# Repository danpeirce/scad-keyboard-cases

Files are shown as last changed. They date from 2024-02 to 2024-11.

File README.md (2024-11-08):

# Corne Inspired Keyboard Case Modified to use a Raspberry Pi Pico

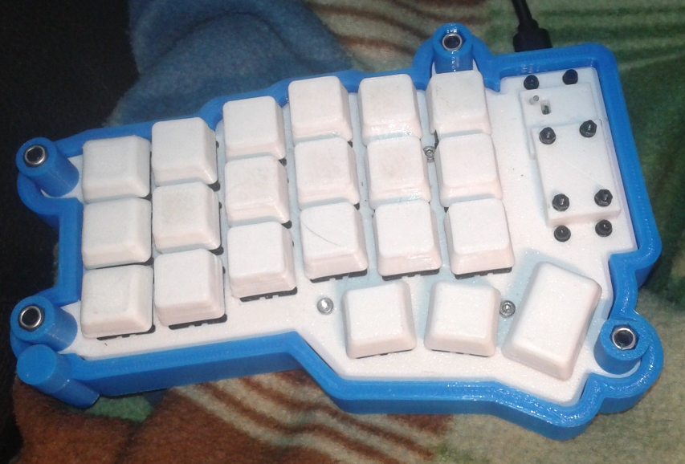
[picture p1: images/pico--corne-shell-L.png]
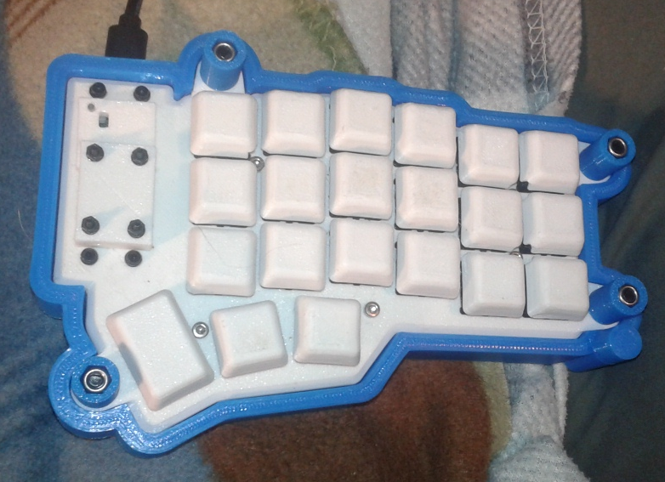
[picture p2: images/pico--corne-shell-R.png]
 

This repository is a fork of https://github.com/Lenbok/scad-keyboard-cases .
That repository is set up to allow the generation of generalized keyboard cases using
a python script to generate a base OpenSCAD design. There was already and example of a Corne case in the original repository so I have used that example as a 
starting point. I wanted that basic physical switch layout but 
also adjusted the case to permit the use of the Raspberry Pi Pico microcontroller board. The Pico required more space than the orignal MCU.
A TPU shell and guard posts were added. Also added tending pegs and internal spacers (spacers go inside shell).

Screws were added to hold it together.

* M2 x16
* M2.5 to connect top to base x10 
* M4 with locking nuts for guard posts x8

Standoffs and holes for mounting the Pico board were added. Additional mounting holes were added for small removable covers to allow for future customization.
I am using the two sides of the keyboard without direct connection between them. One customization could possibly be to add connectors for connection to the other 
side of the keyboard.

* https://datasheets.raspberrypi.com/pico/pico-datasheet.pdf

Files created prior to 2024 are from the original repository. Files specific to this fork are all modified or created in 2024.

## Added Tenting Supports

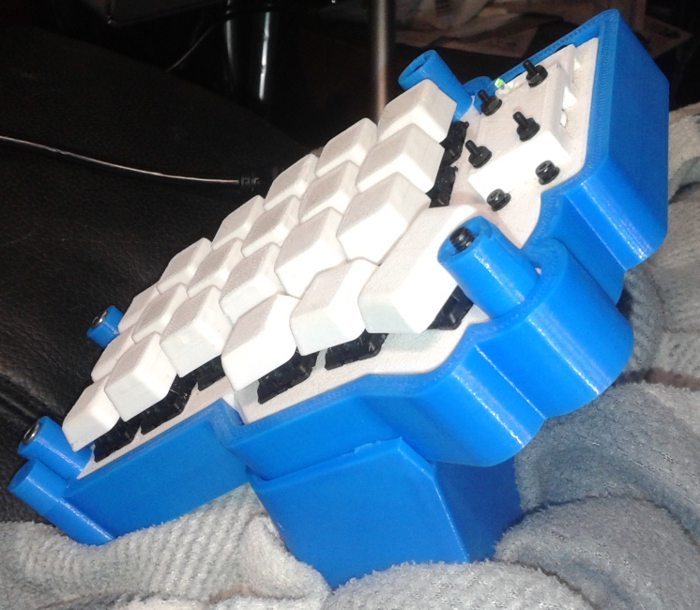
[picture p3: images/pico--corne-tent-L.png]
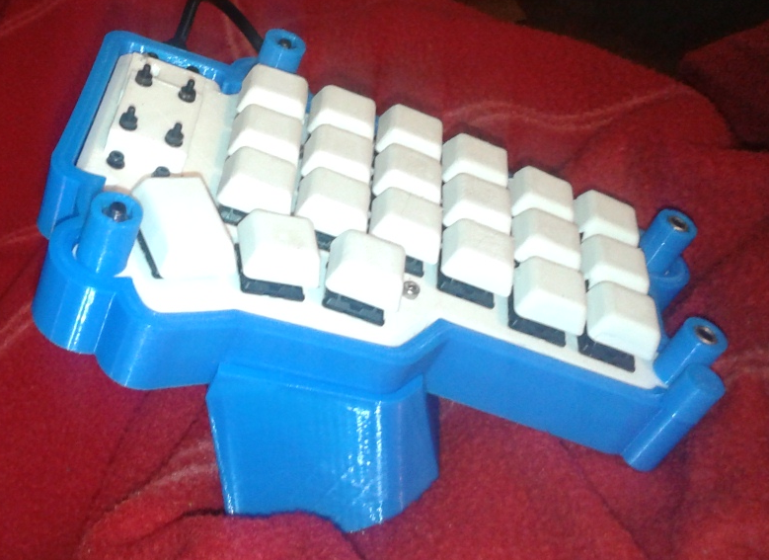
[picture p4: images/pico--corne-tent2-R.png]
 

Each side of the keyboard can be press fit into the tenting support. The supports are made of flexible TPU but have enough infill to be semi-rigid.
	 
## Pico-Corne Keyboard

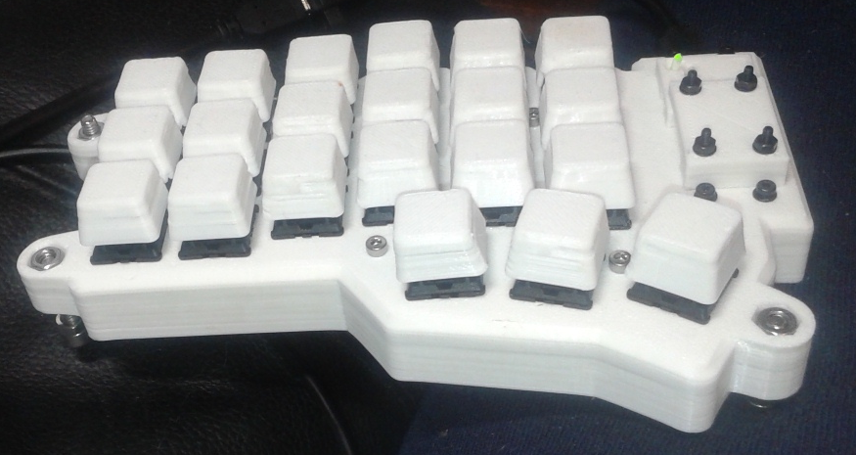
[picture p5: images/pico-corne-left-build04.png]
 

* Light from RPi Pico board piped outside case by short piece of clear PETG filament.
* Covers over Pico board area allow for customization without reprinting whole case. Also contain side
  vents for convective cooling.
* Used crkbd/stls/crkbd-case-top-pico.stl and crkbd/stls/-case-base-pico.stl for left side keyboard. The same file can be mirrored in slicing software to create right side case.
* crkbd/stls/crkbd-case-top-pico.stl and crkbd/stls/cover_trrs.stl are used as is on both left and right sides.

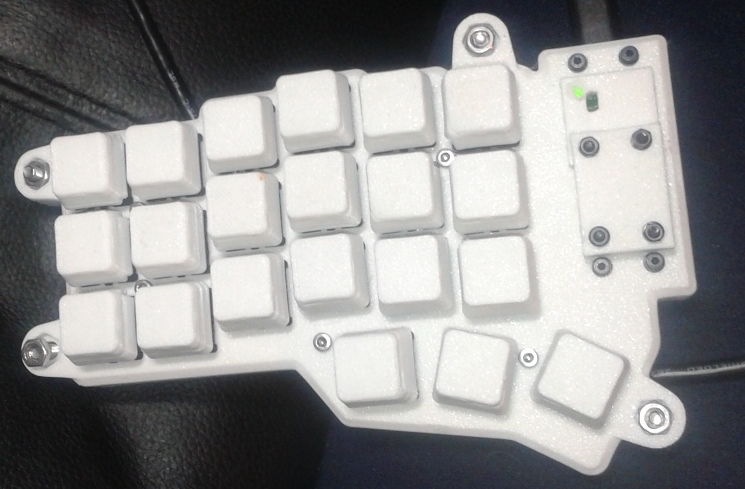
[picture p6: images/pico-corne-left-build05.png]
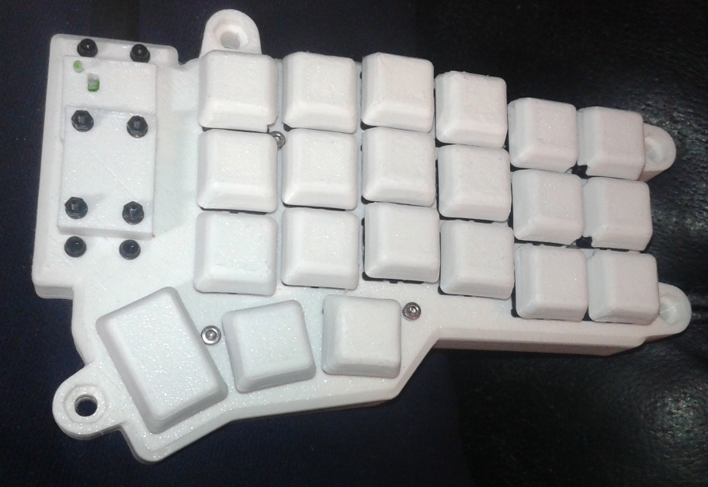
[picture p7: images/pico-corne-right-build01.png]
 

### Construction

Image links to youtube! construction of left side of keyboard (https://www.youtube.com/watch?v=Hs4WmTu5av8)

* The image above is a link to a youtube video showing how the parts of the left side of the keyboard go together. This video was created using Blender and as such is CGI.
* The images below are photographs of the actual physical keyboard.

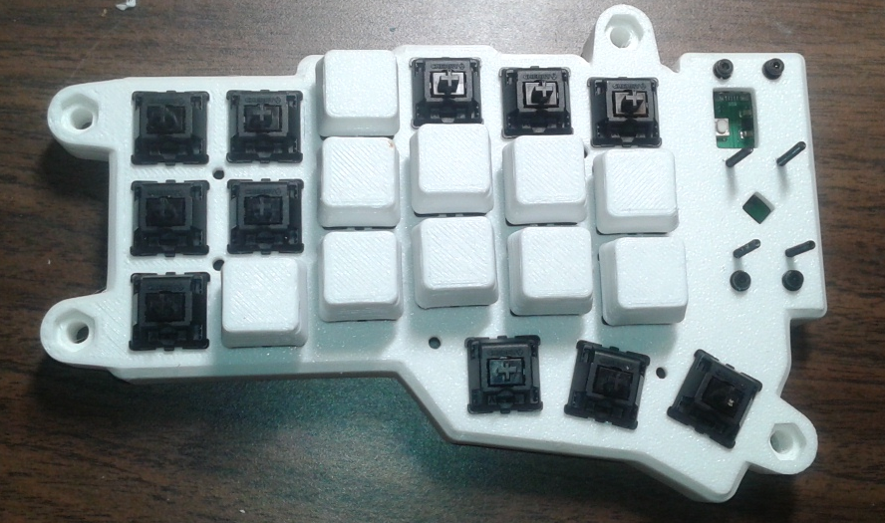
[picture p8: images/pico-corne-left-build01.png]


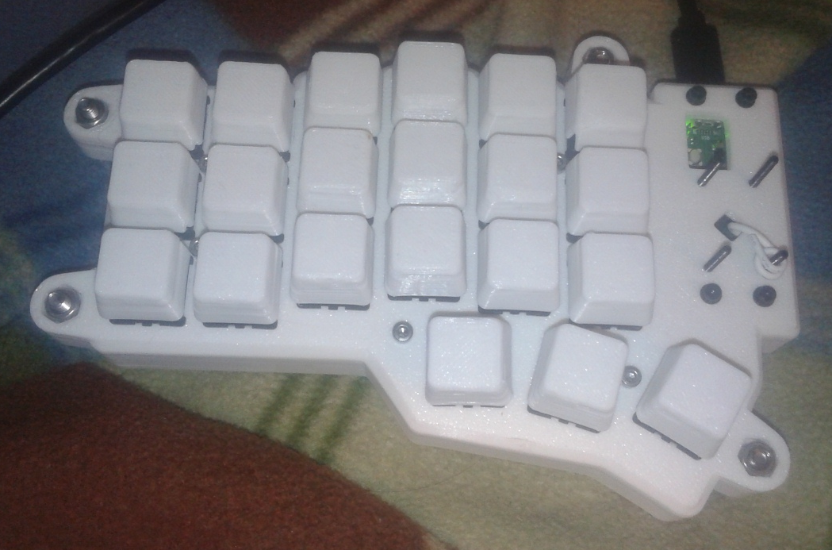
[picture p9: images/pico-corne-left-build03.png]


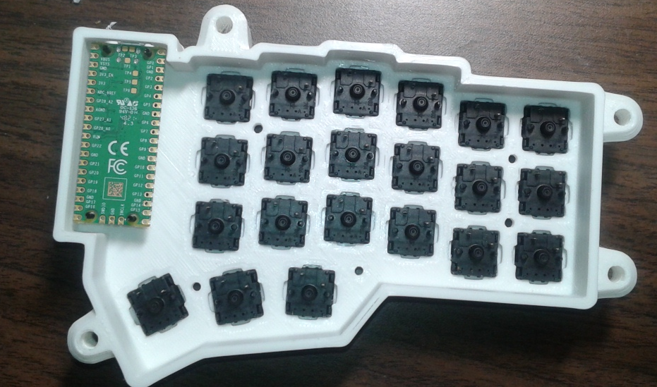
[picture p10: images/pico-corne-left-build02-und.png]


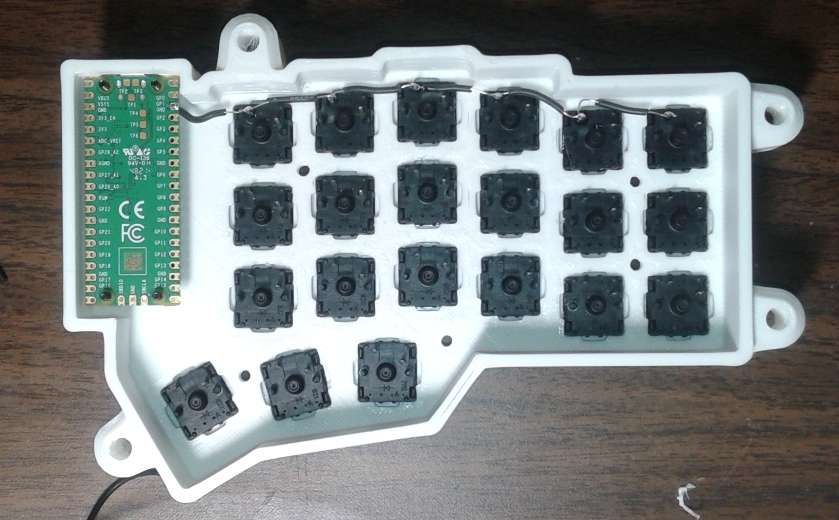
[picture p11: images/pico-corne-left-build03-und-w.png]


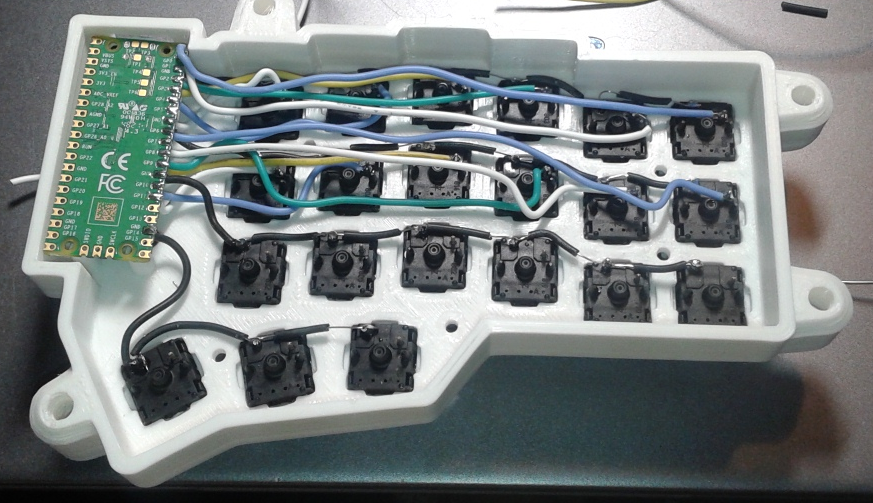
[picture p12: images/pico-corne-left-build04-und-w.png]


#### Protective Shell

Added a TPU protective shell. The intent is to protect the PLA case from possible impacts from drops or knocks.

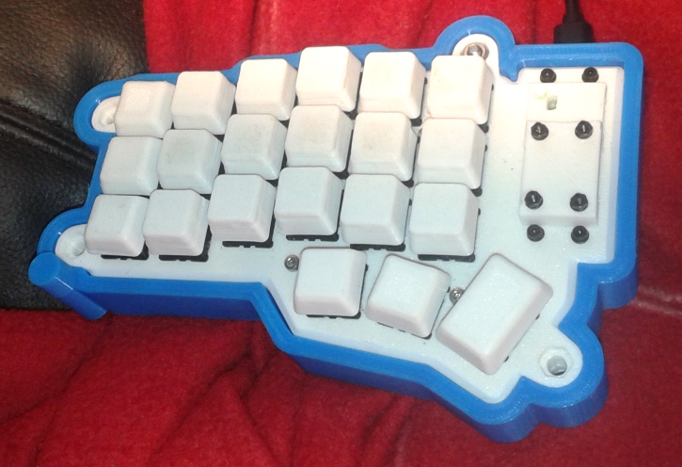
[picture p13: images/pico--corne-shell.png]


## Firmware

Firmware for this project can be found at https://github.com/danpeirce/pico-corne 

## Keycaps

Initially used the following keycaps
 
* [https://www.printables.com/model/808496-flat-top-keycaps-mx-cherry-with-cutouts-for-m25-sc](https://www.printables.com/model/808496-flat-top-keycaps-mx-cherry-with-cutouts-for-m25-sc)

but later found these ones which suited my split keyboard better:

* [https://www.printables.com/model/821325-cherry-mx-compatible-keycaps-flat-top](https://www.printables.com/model/821325-cherry-mx-compatible-keycaps-flat-top)

## Accommodate a Larger Microcontroller Board

* The Raspberry Pi Pico is a larger board that the one typically used on a Corne Keyboard. The outline of the board needed 
  to be expanded in the region of the MCU to accommodate the larger size.
    * Old Outline of Case
	  
    * New Outline of Case


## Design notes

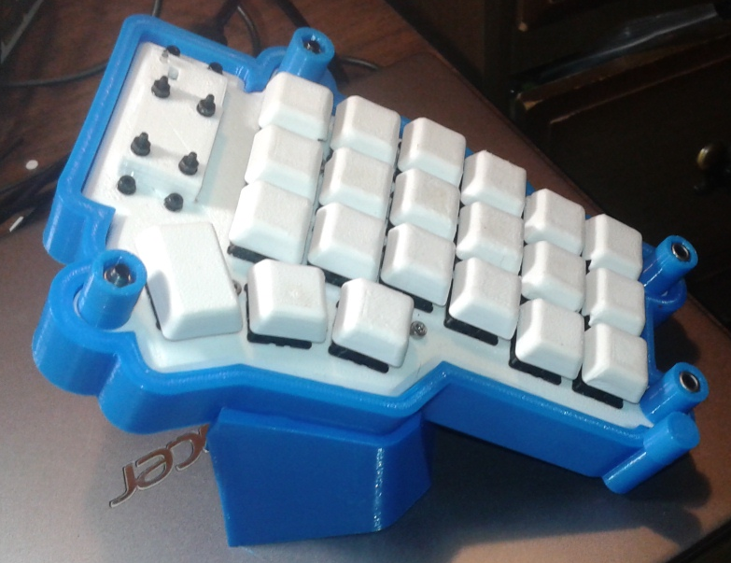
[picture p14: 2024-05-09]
images/pico--corne-tent1-R.png

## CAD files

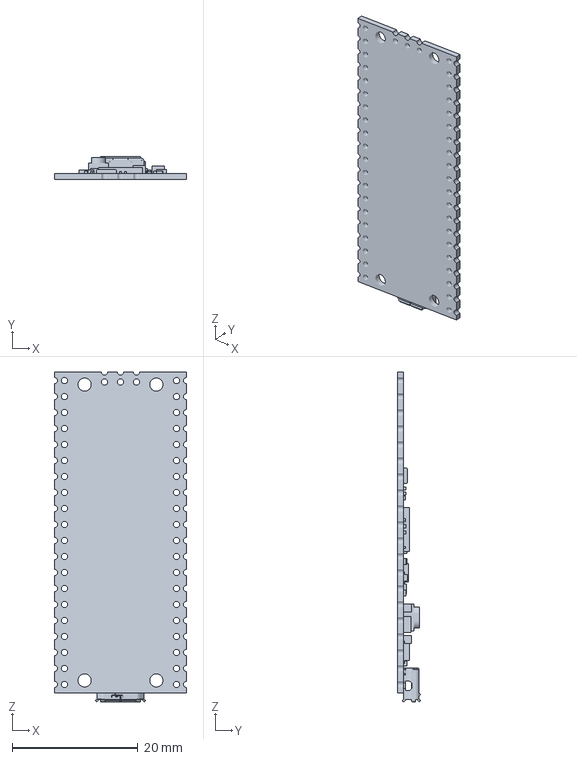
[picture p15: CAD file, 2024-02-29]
crkbd/RaspberryPiPico.amf
21.0 x 3.69 x 52.4 mm

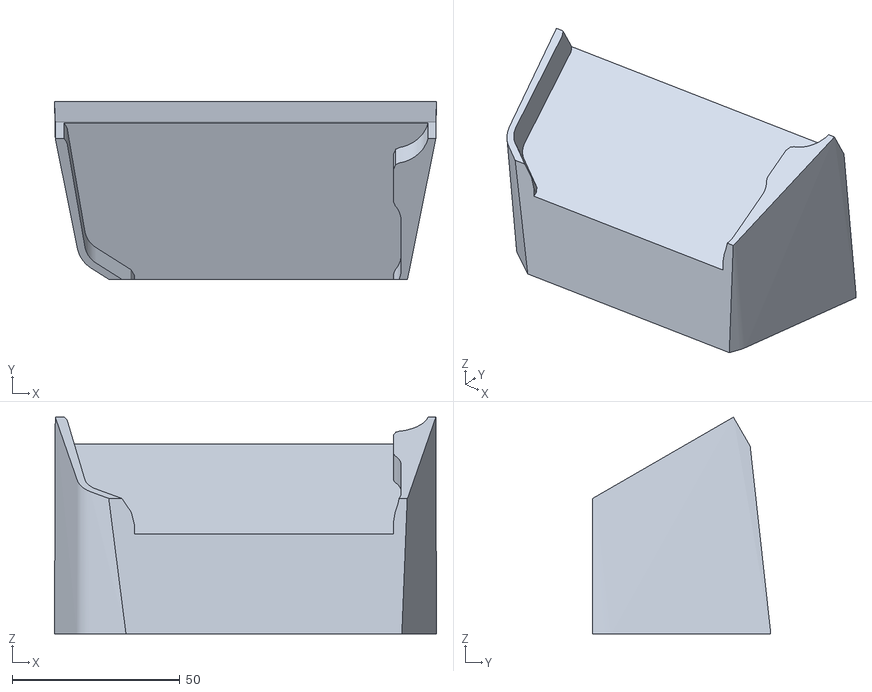
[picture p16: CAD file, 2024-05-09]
crkbd/stls/crkbd-case-tent.stl
114.0 x 53.0 x 64.7

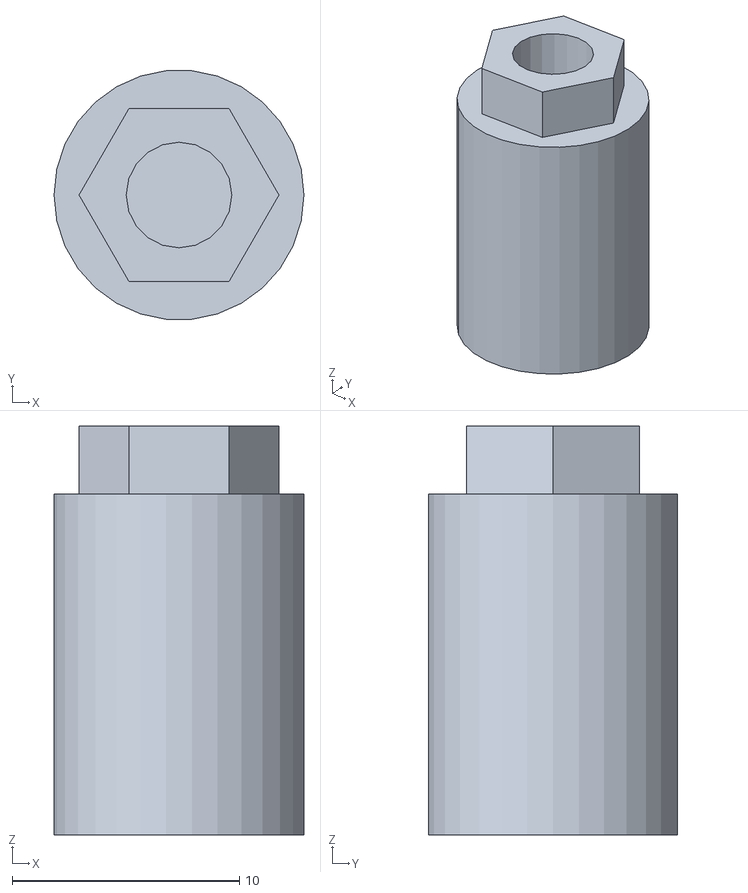
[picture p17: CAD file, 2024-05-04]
crkbd/stls/crkbd-case-t-guardr.stl
11.0 x 10.9 x 18.0

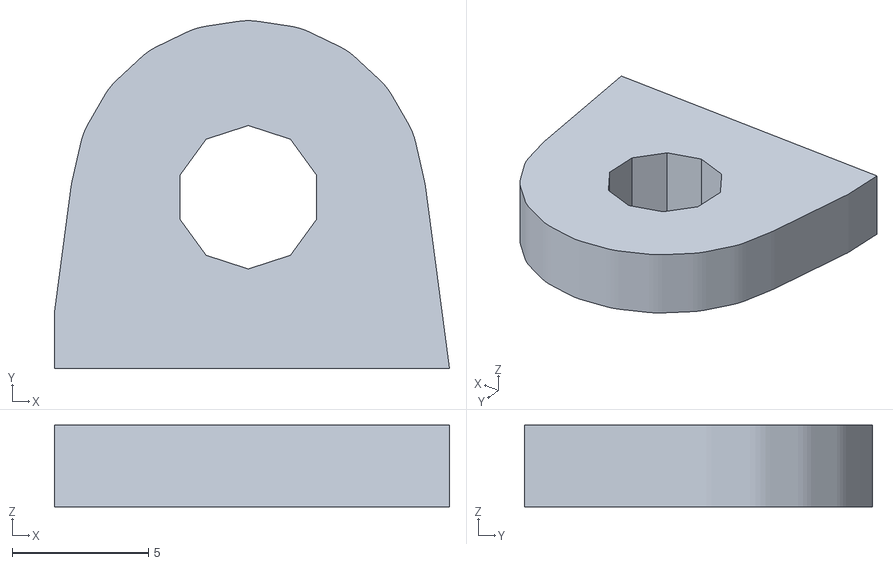
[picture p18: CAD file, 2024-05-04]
crkbd/stls/crkbd-case-t-spacer.stl
14.5 x 12.7 x 3.00

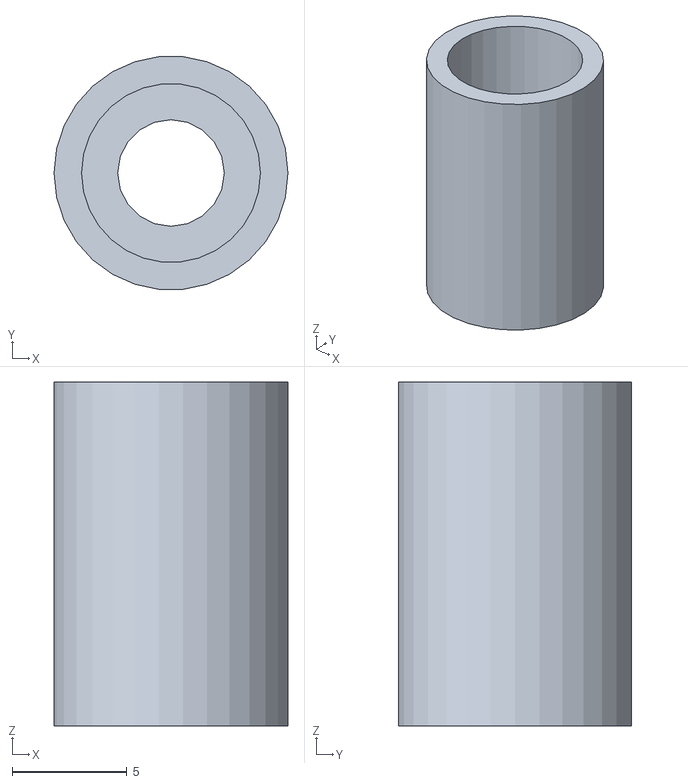
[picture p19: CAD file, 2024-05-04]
crkbd/stls/tent-post-tall.stl
10.2 x 10.1 x 15.0

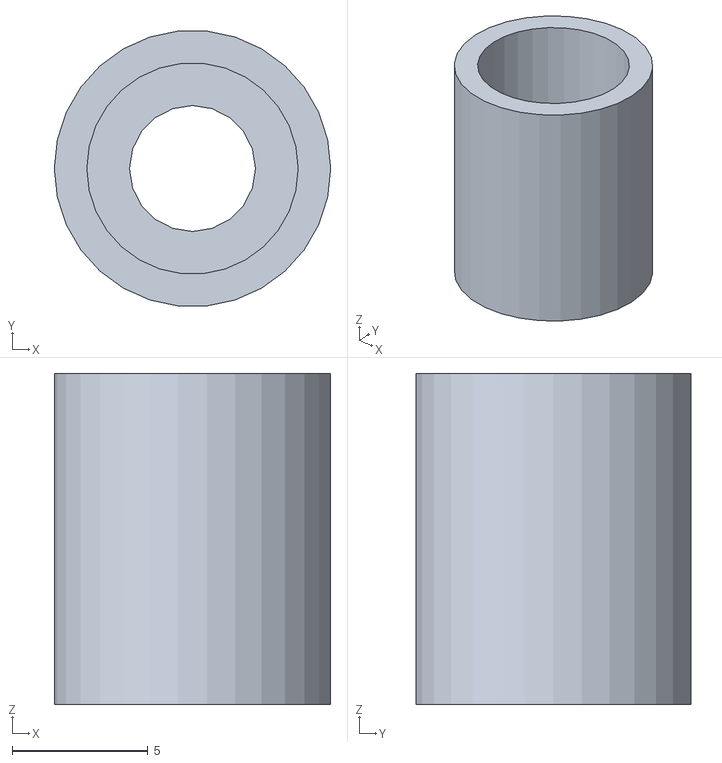
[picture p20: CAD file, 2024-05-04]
crkbd/stls/tent-post-short.stl
10.2 x 10.1 x 12.2

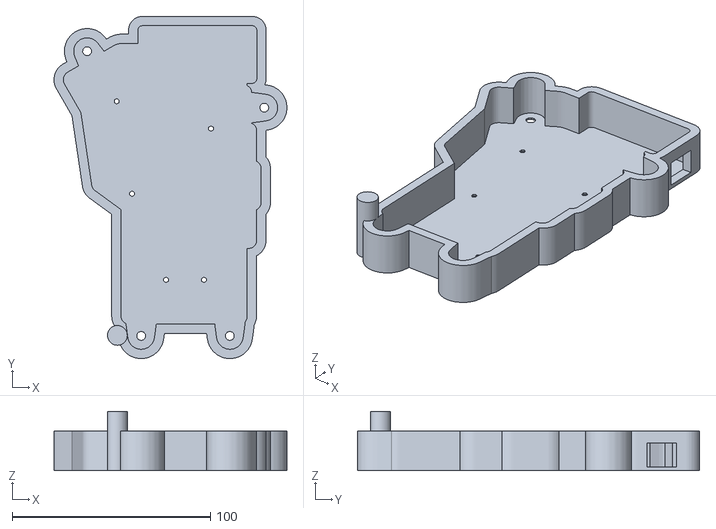
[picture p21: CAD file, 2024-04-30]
crkbd/stls/crkbd-case-cover.stl
117.6 x 172.8 x 30.0

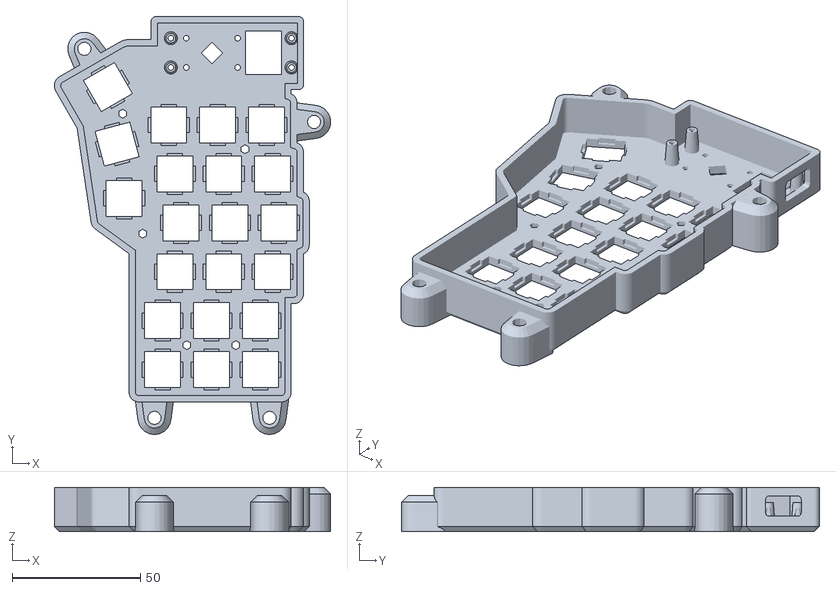
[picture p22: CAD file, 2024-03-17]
crkbd/stls/crkbd-case-top-pico.stl
107.6 x 162.8 x 17.2

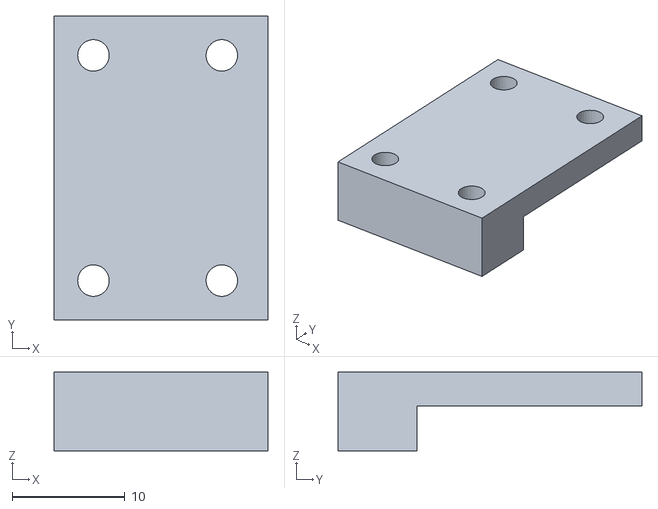
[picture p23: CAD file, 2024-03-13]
crkbd/stls/cover_trrs.stl
19.0 x 27.0 x 7.00

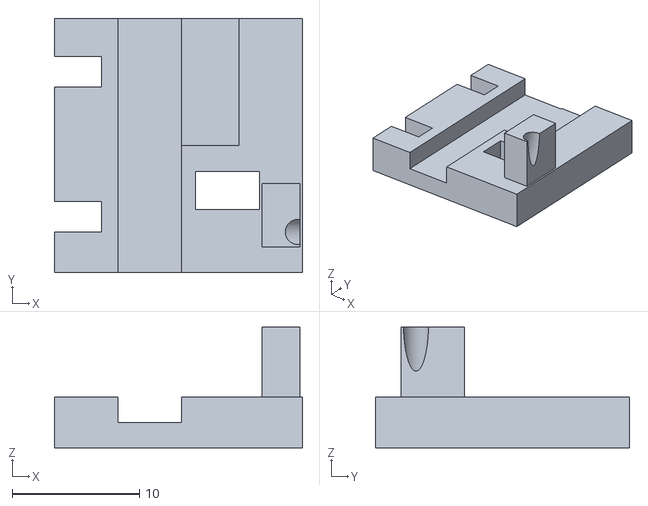
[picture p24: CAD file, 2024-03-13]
crkbd/stls/crkbd-case-led-insert.stl
19.5 x 20.0 x 9.50

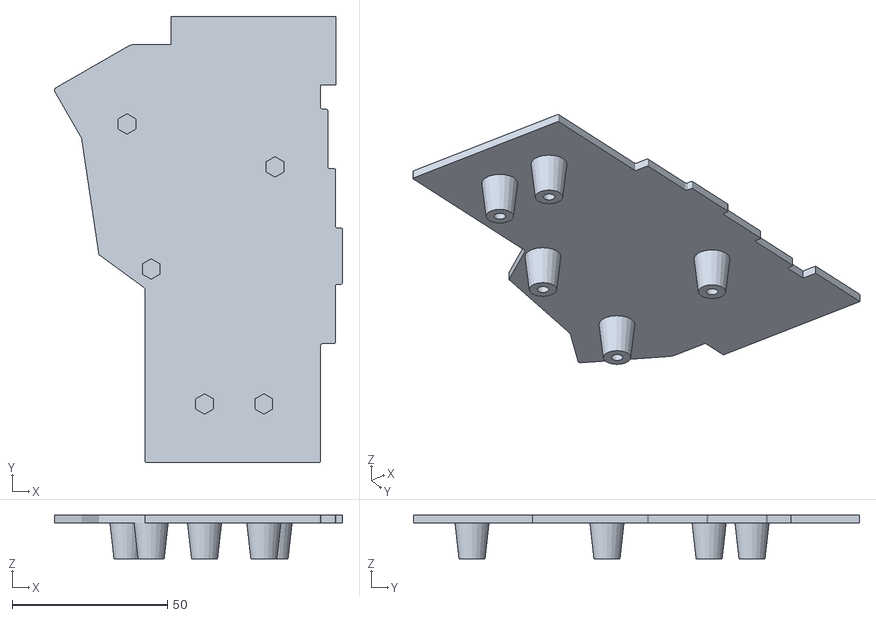
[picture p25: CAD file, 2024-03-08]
crkbd/stls/crkbd-case-base-pico.stl
92.8 x 143.6 x 14.1

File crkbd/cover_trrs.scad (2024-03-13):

offsetx = 3.5;
offsety = 3.5;


difference() {
    union() {
    translate([0,0,4]) cube([19, 27, 3]);
    translate([0.01,0.01,0]) cube([19-0.02, 7, 4.1]);
    }
    translate([offsetx+11.4, offsety, -0.1]) cylinder(h=20, r=2.2/2+0.3, center=false, $fn=30);  // holes mount TRRS connector
    translate([offsetx, offsety, -0.1]) cylinder(h=20, r=2.2/2+0.3, center=false, $fn=30);
    translate([offsetx+11.4, offsety+20, -0.1]) cylinder(h=20, r=2.2/2+0.3, center=false, $fn=30);
    translate([offsetx, offsety+20, -0.1]) cylinder(h=20, r=2.2/2+0.3, center=false, $fn=30);
}

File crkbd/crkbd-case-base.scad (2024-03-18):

///////////////////////////////////////////////////
// Simple Tented Corne Keyboard case
//
// * Single piece combined top plate/outer/tent supports
//
///////////////////////////////////////////////////

include <crkbd-common.scad>
include <../keyboard-case.scad>
include <pico.scad>

theme = 3;
wall_thickness = 2.5;
plate_thickness = 3.2;   // (5mm - max diode height)
depth_offset = 5 + 2 + 2 + 5;       // How much of side wall to include below top plate
bottom_case_height = 5 + 2 + 2; // 11;  // Enough room to house electronics
screw_rad = 3.0 / 2;
tent_attachment_width = 16;
micro_usb_hole_width = 14;
micro_usb_hole_height = 8;

$fa = 1;
$fs = $preview ? 8 : 2;
bezier_precision = $preview ? 0.1 : 0.025;

// Hacky way to select just the left hand keys from a split layout
left_keys = [ for (i = crkbd_layout) if (key_pos(i).x < 8) i ];

crkbd_tent_positions = [
    // [[X, Y], Angle, height]
    [[4.8, -32.2], 180, depth_offset],
    [[4.8, -77.0], 180, depth_offset],
    [[115.5, -19.4], 90, depth_offset + plate_thickness],
    [[140, -102], -30, depth_offset + plate_thickness],
    ];


module simple_micro_usb_hole(hole = true) {
    color("silver") {
        if (hole) {
            translate([0, 1, pcb_thickness+micro_usb_socket_height/2]) rotate([90, 0, 0]) roundedcube([micro_usb_hole_width, micro_usb_hole_height, 10], r=1.5, center=true, $fs=1);
        }
    }
}
module simple_trrs_hole(hole = true) {
    color("silver") {
        if (hole) {
            translate([0, 1, pcb_thickness+micro_usb_socket_height/2]) rotate([90, 0, 0])
                roundedcube([micro_usb_hole_width, micro_usb_hole_height, 10], r=1.5, center=true, $fs=1);
        }
    }
}

module crkbd_case_holes(preview = false) {
    // Case holes for connectors etc. The second version of each is just for preview view
    pcb_offset = plate_thickness - cherry_switch_depth - pcb_thickness;
    // pcb_offset is nominally bottom of crkbd PCB
    translate([142.5, -21.1+3.5, pcb_offset-10]) translate([0, 0, 2 * pcb_thickness]) {
        simple_micro_usb_hole();
        if (preview) {
            %simple_micro_usb_hole(hole = false);
        }
    }
    // TRRS connector - should update to a better shape hole
    translate([138, -34.5, pcb_offset]) translate([0, 0, pcb_thickness]) rotate([0, 0, -90]) {
        simple_trrs_hole();
        if (preview) {
            %simple_trrs_hole(hole = false);
        }
    }
   /* if (preview) {
        %translate([0, 0, plate_thickness - cherry_switch_depth - pcb_thickness])
            crkbd_pcb_assembly();
    }*/
}

module crkbd_top_case(raised = raised) {
    
    difference() {
        union() {
            top_case(left_keys, crkbd_screw_holes, chamfer_faces = true, chamfer_height = raised ? 5 : 2, chamfer_width = 2, raised = raised, tent_positions = crkbd_tent_positions)
                crkbd_outer_profile(raised ? 3 : 2);
            translate([148.1, -70.6, -8.2]) cylinder(h=30-19, r1=3.8/2, r2=5.5/2, center=false, $fn=30); // pico spacer
            translate([148.1-11.4, -70.6, -8.2]) cylinder(h=30-19, r1=3.8/2, r2=5.5/2, center=false, $fn=30);
            translate([148.1, -70.6+47, -8.2]) cylinder(h=30-19, r1=3.8/2, r2=5.5/2, center=false, $fn=30);
            translate([148.1-11.4, -70.6+47, -8.2]) cylinder(h=30-19, r1=3.8/2, r2=5.5/2, center=false, $fn=30);
            
        }
        translate([148.1, -70.6, -26]) cylinder(h=30, r=2.2/2, center=false, $fn=30); // holes mount pico
        translate([148.1-11.4, -70.6, -26]) cylinder(h=30, r=2.2/2, center=false, $fn=30);
        translate([148.1, -70.6+47, -26]) cylinder(h=30, r=2.2/2, center=false, $fn=30);
        translate([148.1-11.4, -70.6+47, -26]) cylinder(h=30, r=2.2/2, center=false, $fn=30);
        translate([148.1, -70.6+26, -26]) cylinder(h=30, r=2.2/2, center=false, $fn=30);  // holes mount TRRS connector
        translate([148.1-11.4, -70.6+26, -26]) cylinder(h=30, r=2.2/2, center=false, $fn=30);
        translate([148.1, -70.6+26-20, -26]) cylinder(h=30, r=2.2/2, center=false, $fn=30);
        translate([148.1-11.4, -70.6+26-20, -26]) cylinder(h=30, r=2.2/2, center=false, $fn=30);
        translate([148.1-11.4/2, -70.6+26-20/2, -26]) cylinder(h=30, r=6/2*1.4, center=false, $fn=4); // hole pass wires
        translate([0, 0, 0]) crkbd_case_holes(true);
        translate([0, 0, -1]) linear_extrude(height = 30, center = false, convexity = 3) 
            //offset(delta = 1, chamfer = false, $fn = 20) // Delta gives sharp interiors
            difference() {
            //crkbd_left_top_window();
            // Ensure some removable supports
            // for (y = [-31, -47, -65]) translate([100, y]) square([100, 1.2], center = false);

        }
    }
}

module crkbd_bottom_case(raised = raised) {
    translate([0,0,3.0+0.01]) 
              screw_positions(crkbd_screw_holes) cylinder(r= screw_rad+0.3+1, h = 0.2, $fn=8); // sacrificial
    difference() {
        union() {
            color(case_color) linear_extrude(height = wall_thickness, center = false, convexity = 3) crkbd_left_bottom();
            translate([0,0,wall_thickness]) 
              screw_positions(crkbd_screw_holes) cylinder(r1 = 3+2+0.5,r2 = screw_rad+0.3+1.2*2, h = depth_offset-2.4, $fn=20);
        }
            translate([0, 0, -wall_thickness]) 
              screw_positions(crkbd_screw_holes) cylinder(r = screw_rad+0.3, h = 4+wall_thickness+depth_offset, $fn=20);
            translate([0, 0, -0.1]) screw_positions(crkbd_screw_holes) cylinder(r = 6/2+0.3, h = 3.1, $fn=6);
    }
}

holder_offset = [9.685, -112.5, 0];
module crkbd_holder_profile() {
    translate(holder_offset) square([119.7, 30], center = false);
}

module crkbd_carrier_profile(expand = 4, holder = false) {
    crkbd_outer_profile(expand);
    crkbd_expand_profile(expand) {
        // Space for magnetic micro usb plug
        translate([129, -33.3]) square([11, 10], center = false);
        // Compartment for cables, tent legs etc
        if (holder) {
            crkbd_holder_profile();
        }
    }
}

module crkbd_carrier_inset() {
    tolerance = 0.3;
    for (m = [0, 1]) mirror([0, 0, m]) translate([0, 0, -3.5]) difference() {
        render() chamfer_extrude(height = 4, chamfer = 2, width = 2, faces = [false, false], $fn = 25)
            difference() {
            crkbd_outer_profile(2 + tolerance + 0.1);
            crkbd_outer_profile(tolerance);
        }
        translate([0, 0, -1.5]) render() chamfer_extrude(height = 5, chamfer = 2, width = 2, faces = [false, true], $fn = 25)
            crkbd_outer_profile(2 + tolerance);
        translate([127, -30.3, -5]) cube([18, 10, 10], center = false);
        translate([140, -83.5, -5]) cube([10, 18, 10], center = false);

   }
}
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

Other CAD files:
crkbd/stls/crkbd-case-t-guard-mod1.stl
crkbd/stls/crkbd-case-t-guard-mod.stl
crkbd/crkbd-case-cover.scad
crkbd/crkbd-case-enclosure-mod.scad
crkbd/crkbd-case-led-insert.scad
crkbd/crkbd-case-t-guard-mod.scad
crkbd/crkbd-case-t-guard-mod1.scad
crkbd/crkbd-case-t-guardr.scad
crkbd/crkbd-case-t-spacer.scad
crkbd/crkbd-case-tent.scad
crkbd/crkbd-case-top.scad
crkbd/crkbd-common.scad
crkbd/orig/crkbd-mods.scad
crkbd/pico.scad
crkbd/tent-post.scad

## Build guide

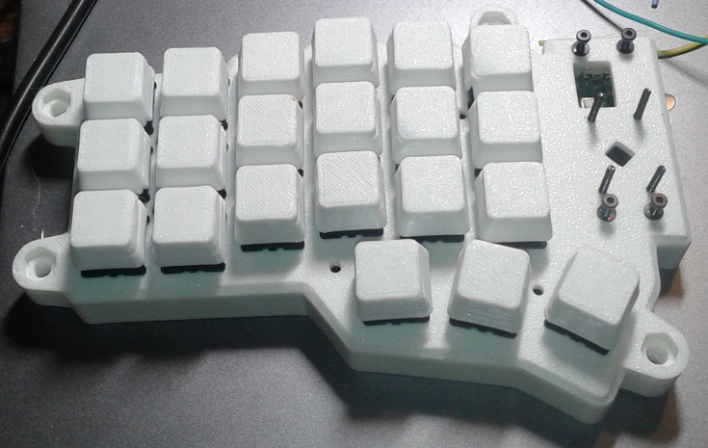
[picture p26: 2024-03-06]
images/pico-corne-left-build02.png

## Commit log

2024-02-06 exploring crkbd files
    [crkbd-case-alt.scad, crkbd-case-alt.stl, crkbd-case-minimal.scad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]
2024-02-06 modified crkbd-case-minimal.scad for RPi Pico and no PCB
    [crkbd-case-alt.stl, crkbd-case-minimal-top-rpi-pico.stl, crkbd-case-minimal.scad]
2024-02-29 modified crone for RPi Pico
    [RaspberryPiPico.amf, crkbd-case-top.scad, crkbd-common.scad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]
2024-03-01 update readme.md - add files
    [crkbd-case-top-pico.stl]
2024-03-06 added modified bottom case or base
    [crkbd-case-base-pico.stl, crkbd-case-base.scad, pico-washers.scad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]
2024-03-08 spacer shorter 2.4 mm
    [crkbd-case-base-pico.stl, crkbd-case-base.scad]
2024-03-13 added led and trrs covers
    [cover_trrs.scad, cover_trrs.stl, crkbd-case-led-insert.scad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]
2024-03-17 altered top case so can be mirrored for right side
    [crkbd-case-led-insert.scad, crkbd-case-top-pico.stl, crkbd-case-top.scad]
2024-03-17 removed files not relavent to this branch
    [BottomR.stl, Foot_Mold.stl, Micro_USB_Spacer.stl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]
2024-03-18 mod to comments and removed files not needed
    [crkbd-case-base.scad, crkbd-case-encoder-mount.scad, crkbd-case-top.scad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]
2024-03-18 removed stl files unrelated to my version
    [crkbd-case-alt-bottom.stl, crkbd-case-alt-top.stl, crkbd-case-bottom.stl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]
2024-04-30 added protective TPU cover
    [crkbd-case-cover.scad, crkbd-case-cover.stl]
2024-05-04 add guards and tenting
    [crkbd-case-enclosure-mod.scad, crkbd-case-t-guard-mod.scad, crkbd-case-t-guard-mod.stl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]
2024-05-09 added tenting support
    [crkbd-case-tent.scad, crkbd-case-tent.stl]
